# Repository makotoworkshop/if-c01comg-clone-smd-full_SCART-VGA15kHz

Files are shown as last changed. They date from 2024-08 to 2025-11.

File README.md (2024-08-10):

IF-C01COMG Clone board SMD Full size_SCART-VGA15kHz

This is a full sized version of the IF-C01COMG board for JVC pro monitors (TM-Hxx50CG) and some others...

It's basically the THT base board I made some months ago, with most components changed to SMD.

Credit goes to James Vanderloeff for the dual input idea.

Board is for now completely untested...

Finally this is a Kicad 5.1 project :D

You're welcome to clone, sell, re-design and whatever, see LICENSE.

(2021) Martin Hejnfelt (martin@hejnfelt.com)
This work is free. You can redistribute it and/or modify it under the
terms of the Do What The Fuck You Want To Public License, Version 2,
as published by Sam Hocevar. See the LICENSE file for more details.

—————————————————————————————

edit (2024) makotoworkshop.org

For more informations, see https://burogu.makotoworkshop.org/index.php?post/2024/08/08/jvc-rgb
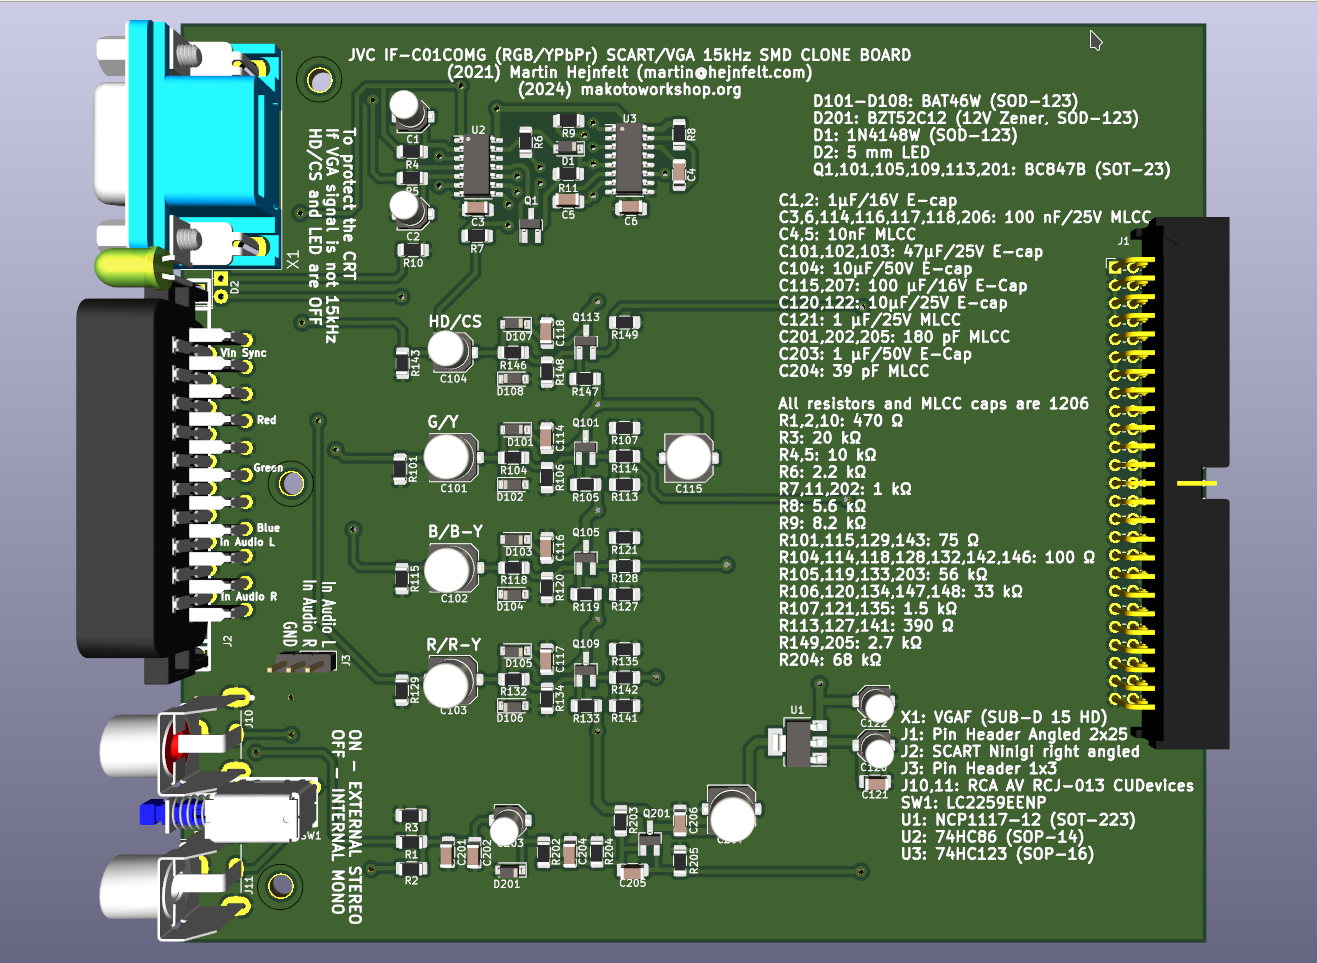
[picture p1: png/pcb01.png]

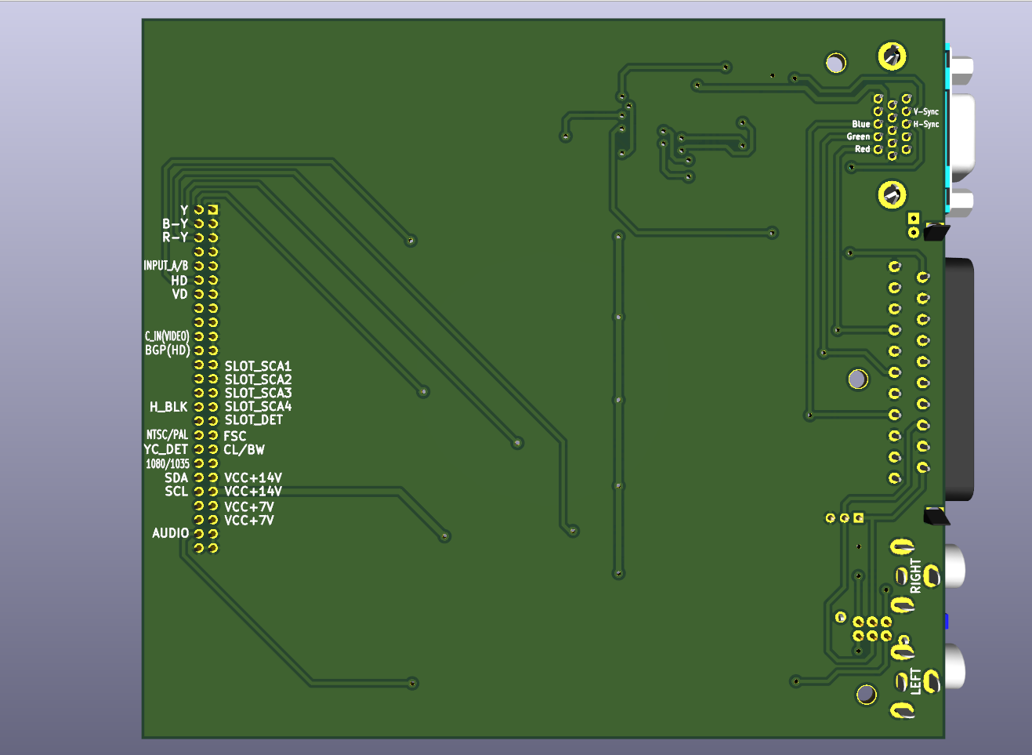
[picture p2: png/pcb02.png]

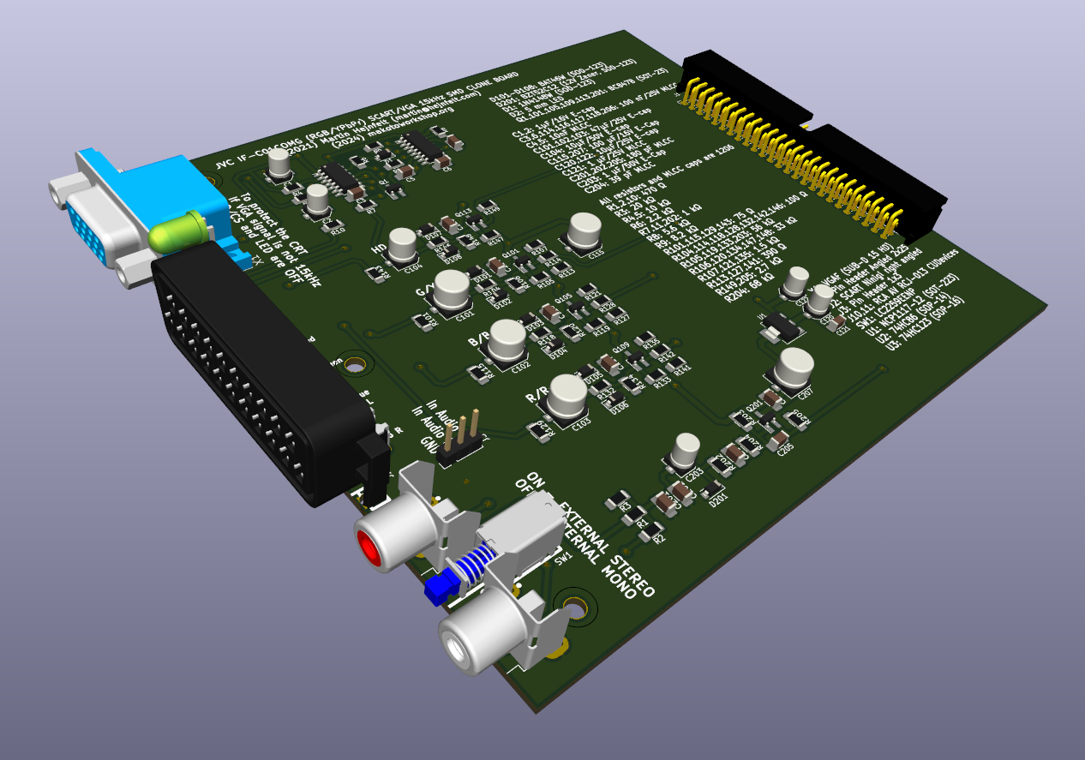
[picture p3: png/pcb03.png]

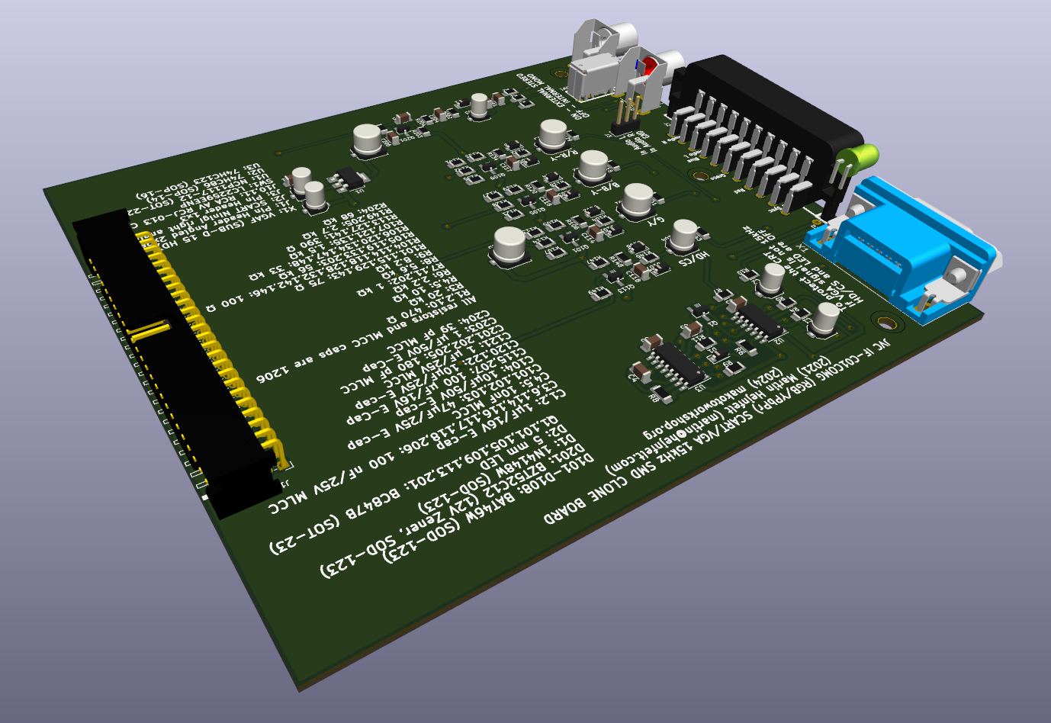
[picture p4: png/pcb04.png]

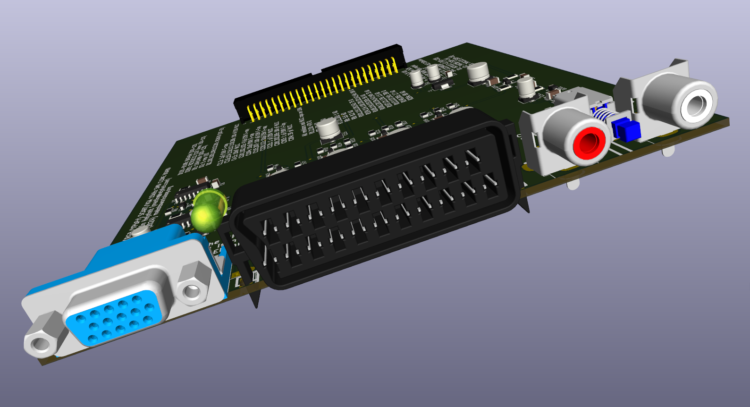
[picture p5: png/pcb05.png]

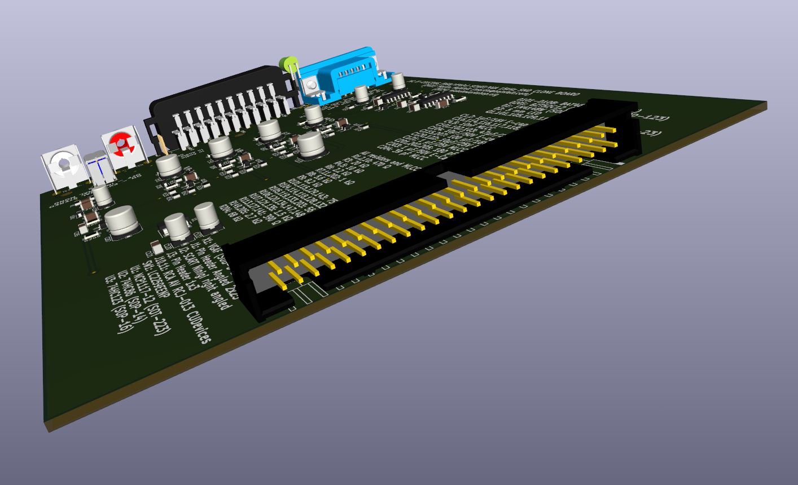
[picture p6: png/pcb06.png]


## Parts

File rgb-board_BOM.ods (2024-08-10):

Ref | Qnty | Stock | Value | Cmp name | Footprint | Description
C1, C2, | 2 | 19 | 1uF/16V | CP | Capacitor_SMD:C_Elec_4x5.4
C3, C6, C114, C116, C117, C118, C206, | 7 | 26 | 100nF | C | Capacitor_SMD:C_1206_3216Metric_Pad1.33x1.80mm_HandSolder
C4, C5, | 2 | 12 | 10nF | C | Capacitor_SMD:C_1206_3216Metric_Pad1.33x1.80mm_HandSolder
C101, C102, C103, | 3 | 20 | 47uF/25V | CP | Capacitor_SMD:C_Elec_6.3x5.4
C104, | 1 | 20 | 10uF/50V | CP | Capacitor_SMD:C_Elec_5x5.4
C115, C207, | 2 | 24 | 100uF/16V | CP | Capacitor_SMD:C_Elec_6.3x5.4
C120, C122, | 2 | 20 | 10uF/25V | CP | Capacitor_SMD:C_Elec_4x5.4
C121, | 1 | ALIE | 1uF/25V | C | Capacitor_SMD:C_1206_3216Metric_Pad1.33x1.80mm_HandSolder
C201, C202, C205, | 3 | ALIE | 180pF | C | Capacitor_SMD:C_1206_3216Metric_Pad1.33x1.80mm_HandSolder
C203, | 1 | 19 | 1uF/50V | CP | Capacitor_SMD:C_Elec_4x5.4
C204, | 1 | ALIE | 39pF | C | Capacitor_SMD:C_1206_3216Metric_Pad1.33x1.80mm_HandSolder
D1, | 1 | ALIE | 1N4148W | 1N4148W | Diode_SMD:D_SOD-123 | 75V 0.15A Fast Switching Diode, SOD-123
D2, | 1 | ok | LED_Small_Filled | LED_Small_Filled | LED_THT:LED_D5.0mm_Horizontal_O1.27mm_Z3.0mm | Light emitting diode, small symbol, filled shape
D101, D102, D103, D104, D105, D106, D107, D108, | 8 | ALIE | BAT46W | D | Diode_SMD:D_SOD-123
D201, | 1 | ALIE | BZT52C12 | D_Zener | Diode_SMD:D_SOD-123
J1, | 1 | ALIE | Conn_02x25_Odd_Even | Conn_02x25_Odd_Even | Pin_Headers:Pin_Header_Angled_2x25_Pitch2.54mm
J2, | 1 | ok | SCART-F | SCART-F | ninigi-scart-ra:NINIGI-SCART-RA
J10, J11, | 2 | ALIE | Conn_Coaxial | Conn_Coaxial | rcj-41x:RCJ-04X
Q1, | 1 | 199 | BC847B | BC847 | Package_TO_SOT_SMD:SOT-23_Handsoldering | 0.1A Ic, 45V Vce, Small Signal NPN Transistor, TO-92
Q101, Q105, Q109, Q113, Q201, | 5 | 199 | BC850C | Q_NPN_BEC | Package_TO_SOT_SMD:SOT-23_Handsoldering | NPN transistor, base/emitter/collector
R1, R2, R10, | 3 | 10 | 470R | R | Resistor_SMD:R_1206_3216Metric_Pad1.30x1.75mm_HandSolder
R3, | 1 | ALIE | 20K | R | Resistor_SMD:R_1206_3216Metric_Pad1.30x1.75mm_HandSolder
R4, R5, | 2 | 9 | 10k | R | Resistor_SMD:R_1206_3216Metric_Pad1.30x1.75mm_HandSolder
R6, | 1 | 14 | 2k2 | R | Resistor_SMD:R_1206_3216Metric_Pad1.30x1.75mm_HandSolder
R7, R11, R202, | 2 | ALIE | 1k | R | Resistor_SMD:R_1206_3216Metric_Pad1.30x1.75mm_HandSolder
R8, | 1 | ALIE | 5k6 | R | Resistor_SMD:R_1206_3216Metric_Pad1.30x1.75mm_HandSolder
R9, | 1 | ALIE | 8k2 | R | Resistor_SMD:R_1206_3216Metric_Pad1.30x1.75mm_HandSolder
R101, R115, R129, R143, | 4 | ALIE | 75R | R | Resistor_SMD:R_1206_3216Metric_Pad1.30x1.75mm_HandSolder
R104, R114, R118, R128, R132, R142, R146, | 7 | 26 | 100R | R | Resistor_SMD:R_1206_3216Metric_Pad1.30x1.75mm_HandSolder
R105, R119, R133, R203, | 4 | ALIE | 56k | R | Resistor_SMD:R_1206_3216Metric_Pad1.30x1.75mm_HandSolder
R106, R120, R134, R147, R148, | 5 | 10 | 33k | R | Resistor_SMD:R_1206_3216Metric_Pad1.30x1.75mm_HandSolder
R107, R121, R135, | 3 | ALIE | 1.5k | R | Resistor_SMD:R_1206_3216Metric_Pad1.30x1.75mm_HandSolder
R113, R127, R141, | 3 | ALIE | 390R | R | Resistor_SMD:R_1206_3216Metric_Pad1.30x1.75mm_HandSolder
R149, R205, | 2 | ALIE | 2.7k | R | Resistor_SMD:R_1206_3216Metric_Pad1.30x1.75mm_HandSolder
R204, | 1 | ALIE | 68K | R | Resistor_SMD:R_1206_3216Metric_Pad1.30x1.75mm_HandSolder
SW1, | 1 | 9 | SW_DPDT_x2 | SW_DPDT_x2 | LC2259:LC2259
U1, | 1 | ALIE | NCP1117-12 | NCP1117-12_SOT223 | Package_TO_SOT_SMD:SOT-223-3_TabPin2 | 1A Low drop-out regulator, Fixed Output 12V, SOT-223
U2, | 1 | ALIE | 74HC86 | 74HC86 | Package_SO:SOIC-14_3.9x8.7mm_P1.27mm | Quad 2-input XOR
U3, | 1 | ALIE | 74HC123 | 74HC123 | Package_SO:SOIC-16_3.9x9.9mm_P1.27mm | Dual retriggerable monostable multivibrator
X1, | 1 |  | VGAF | VGAF | HD15:HD15_B-HD15F

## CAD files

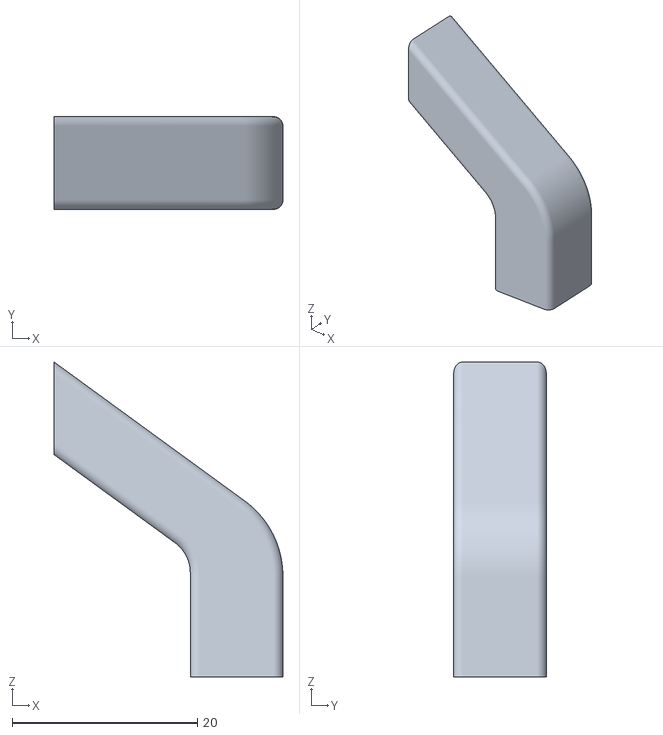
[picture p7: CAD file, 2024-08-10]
FreeCAD/Façade-ArcsNum003.stl
24.7 x 10.0 x 34.0

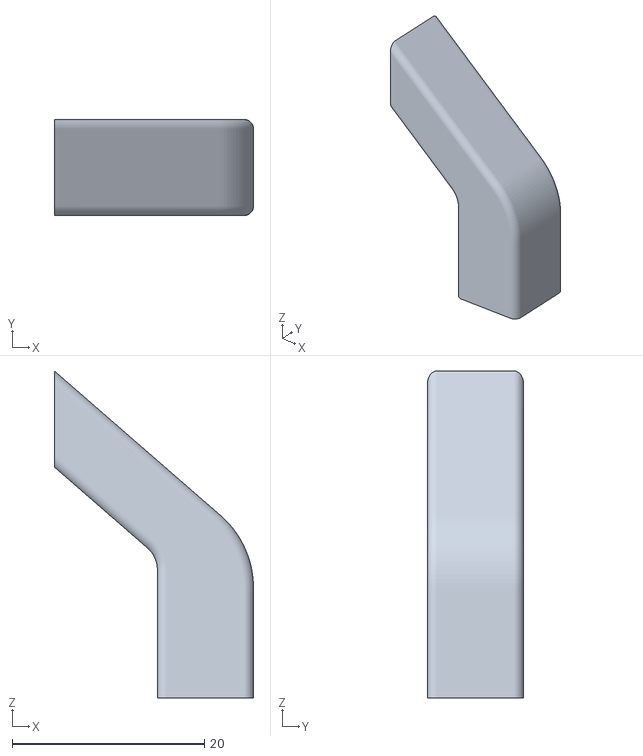
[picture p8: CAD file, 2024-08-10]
FreeCAD/Façade-ArcsNum002.stl
20.7 x 10.0 x 34.0

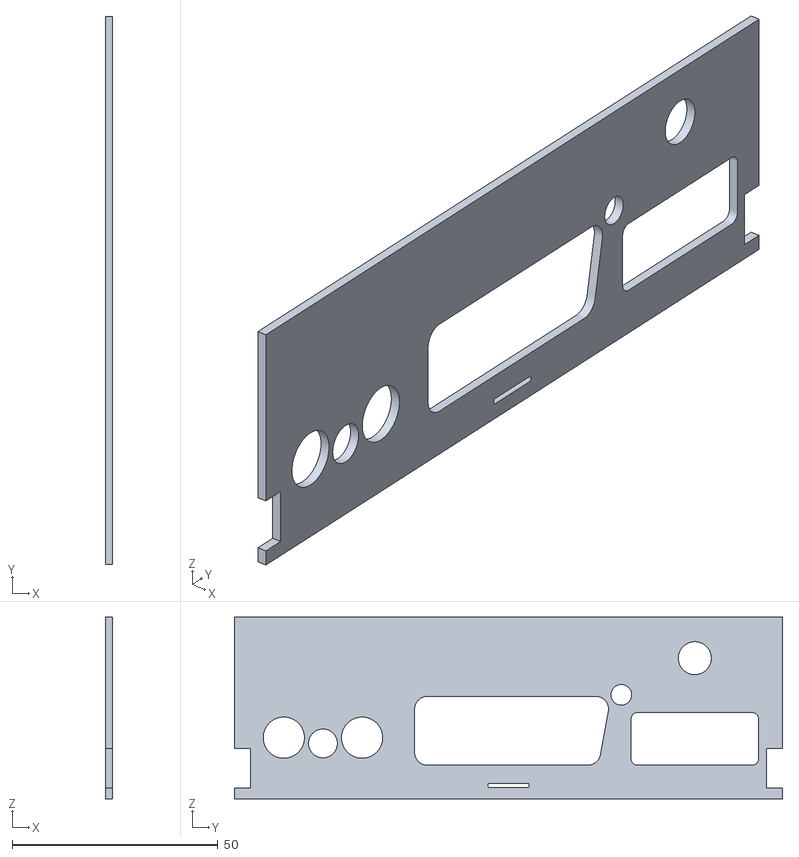
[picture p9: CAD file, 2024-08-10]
FreeCAD/Façade-Façade.stl
1.70 x 133.2 x 44.2

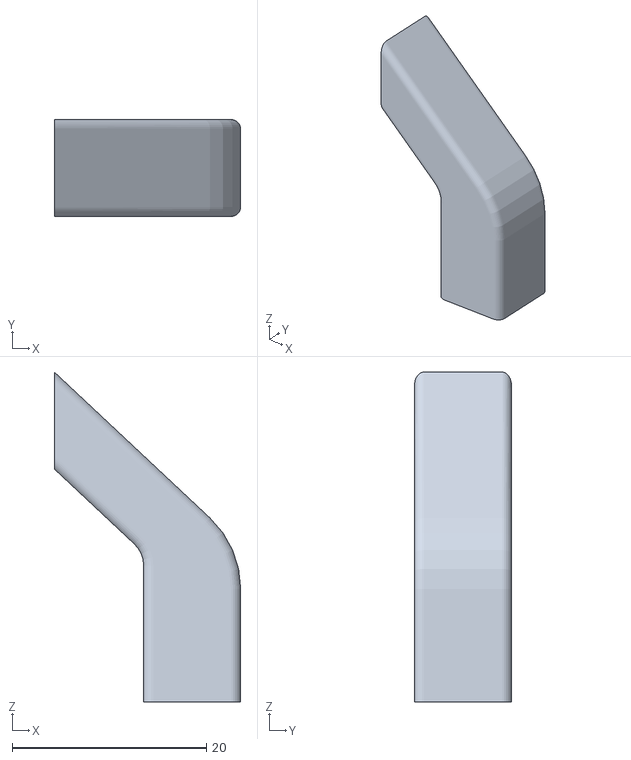
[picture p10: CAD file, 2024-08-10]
FreeCAD/Façade-ArcsNum1.stl
19.2 x 10.0 x 34.0

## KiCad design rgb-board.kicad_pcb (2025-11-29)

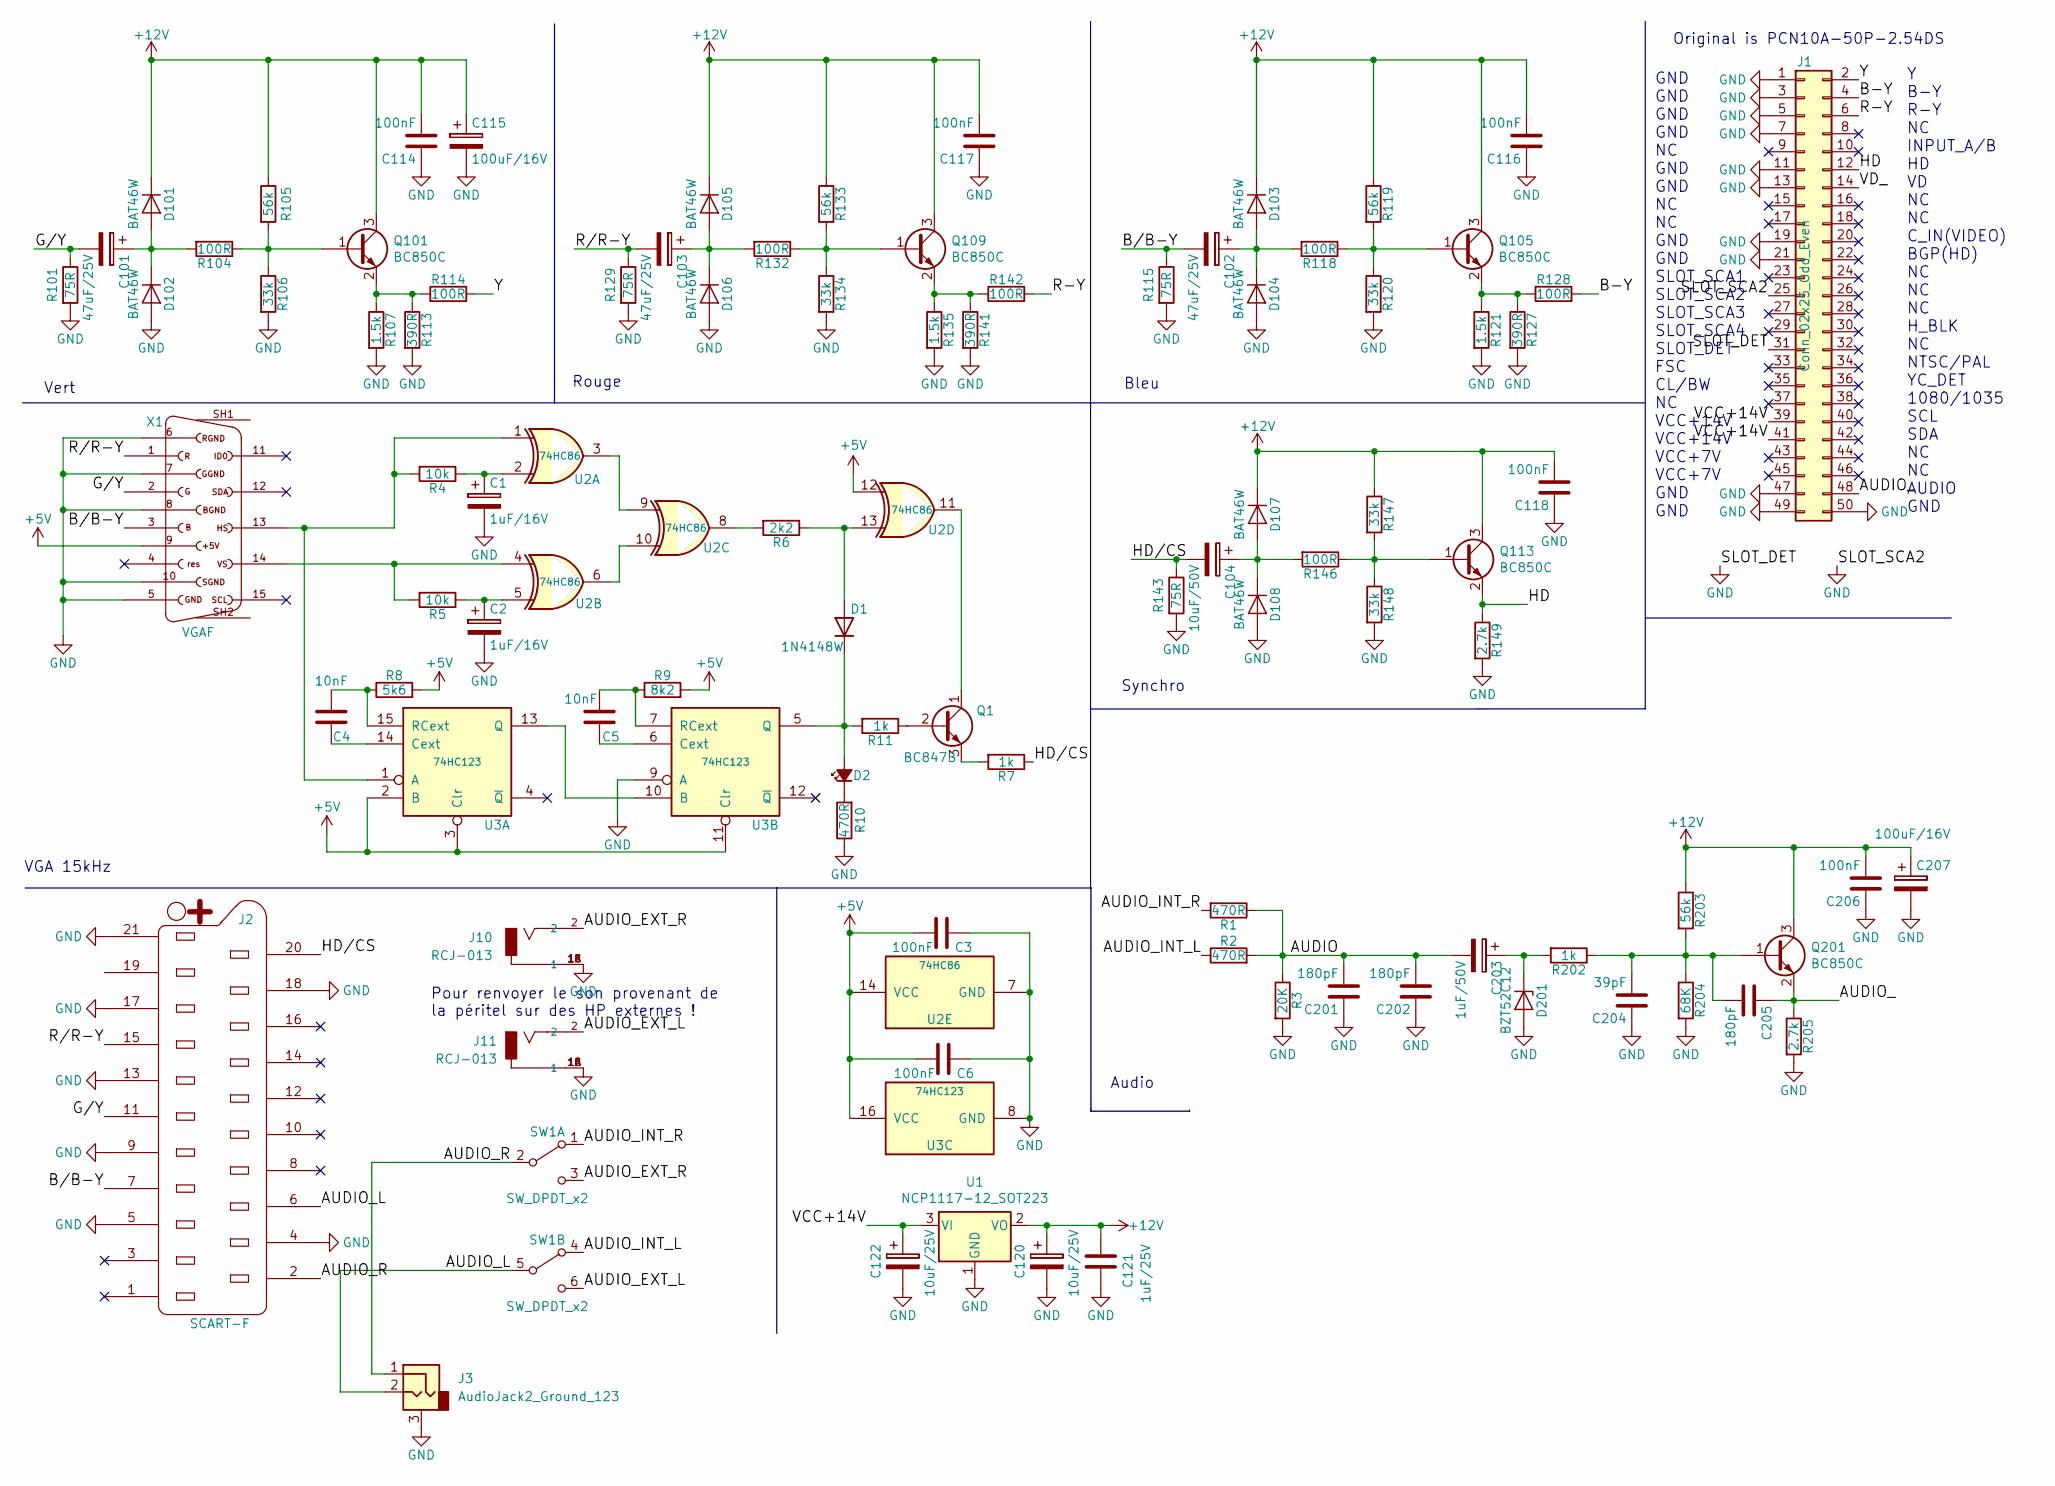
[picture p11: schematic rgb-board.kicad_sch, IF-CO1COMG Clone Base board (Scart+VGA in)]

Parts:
C1, C2: 1uF/16V; C_Elec_4x5.4
C3, C6, C114, C116, C117, C118, C206: 100nF; C_1206_3216Metric_Pad1.33x1.80mm_HandSolder
C4, C5: 10nF; C_1206_3216Metric_Pad1.33x1.80mm_HandSolder
C101, C102, C103: 47uF/25V; C_Elec_6.3x5.4
C104: 10uF/50V; C_Elec_5x5.4
C115, C207: 100uF/16V; C_Elec_6.3x5.4
C120, C122: 10uF/25V; C_Elec_4x5.4
C121: 1uF/25V; C_1206_3216Metric_Pad1.33x1.80mm_HandSolder
C201, C202, C205: 180pF; C_1206_3216Metric_Pad1.33x1.80mm_HandSolder
C203: 1uF/50V; C_Elec_4x5.4
C204: 39pF; C_1206_3216Metric_Pad1.33x1.80mm_HandSolder
D1: 1N4148W; D_SOD-123
D2: LED_Small_Filled; LED_D5.0mm_Horizontal_O1.27mm_Z3.0mm
D101, D102, D103, D104, D105, D106, D107, D108: BAT46W; D_SOD-123
D201: BZT52C12; D_SOD-123
J1: Conn_02x25_Odd_Even; Pin_Header_Angled_2x25_Pitch2.54mm
J2: SCART-F; NINIGI-SCART-RA
J3: AudioJack2_Ground_123; PinHeader_1x03_P2.54mm_Vertical
J10, J11: RCJ-013; CUI_RCJ-013; PART_REV B
Q1: BC847B; SOT-23_Handsoldering
Q101, Q105, Q109, Q113, Q201: BC850C; SOT-23_Handsoldering
R1, R2, R10: 470R; R_1206_3216Metric_Pad1.30x1.75mm_HandSolder
R3: 20K; R_1206_3216Metric_Pad1.30x1.75mm_HandSolder
R4, R5: 10k; R_1206_3216Metric_Pad1.30x1.75mm_HandSolder
R6: 2k2; R_1206_3216Metric_Pad1.30x1.75mm_HandSolder
R7, R11, R202: 1k; R_1206_3216Metric_Pad1.30x1.75mm_HandSolder
R8: 5k6; R_1206_3216Metric_Pad1.30x1.75mm_HandSolder
R9: 8k2; R_1206_3216Metric_Pad1.30x1.75mm_HandSolder
R101, R115, R129, R143: 75R; R_1206_3216Metric_Pad1.30x1.75mm_HandSolder
R104, R114, R118, R128, R132, R142, R146: 100R; R_1206_3216Metric_Pad1.30x1.75mm_HandSolder
R105, R119, R133, R203: 56k; R_1206_3216Metric_Pad1.30x1.75mm_HandSolder
R106, R120, R134, R147, R148: 33k; R_1206_3216Metric_Pad1.30x1.75mm_HandSolder
R107, R121, R135: 1.5k; R_1206_3216Metric_Pad1.30x1.75mm_HandSolder
R113, R127, R141: 390R; R_1206_3216Metric_Pad1.30x1.75mm_HandSolder
R149, R205: 2.7k; R_1206_3216Metric_Pad1.30x1.75mm_HandSolder
R204: 68K; R_1206_3216Metric_Pad1.30x1.75mm_HandSolder
SW1: SW_DPDT_x2; LC2259
U1: NCP1117-12_SOT223; SOT-223-3_TabPin2
U2: 74HC86; SOIC-14_3.9x8.7mm_P1.27mm
U3: 74HC123; SOIC-16_3.9x9.9mm_P1.27mm
X1: VGAF; HD15_B-HD15F

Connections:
+5V: C3.2, C6.2, R8.2, R9.2, U2.12, U2.14 (VCC), U3.2 (B), U3.3 (Clr), U3.11 (Clr), U3.16 (VCC), X1.9; also elsewhere on the board
+12V: C114.2, C115.1, C116.2, C117.2, C118.2, C120.1, C121.2, C206.2, C207.1, D101.1 (K), D103.1 (K), D105.1 (K), D107.1 (K), Q101.3 (C), Q105.3 (C), Q109.3 (C), Q113.3 (C), Q201.3 (C), R105.1, R119.1, R133.1, R147.1, R203.1, U1.2 (VO)
/AUDIO: C201.2, C202.2, C203.2, R1.1, R2.2, R3.1
/AUDIO_: C205.1, J1.48, Q201.2 (E), R205.1
/AUDIO_EXT_L: J11.2, SW1.6 (C)
/AUDIO_EXT_R: J10.2, SW1.3 (C)
/AUDIO_INT_L: R2.1, SW1.4 (A)
/AUDIO_INT_R: R1.2, SW1.1 (A)
/AUDIO_L: J2.6, J3.2, SW1.5 (B)
/AUDIO_R: J2.2, J3.1, SW1.2 (B)
/B-Y: J1.4, R128.2
/B/B-Y: C102.2, J2.7, R115.1, X1.3
/G/Y: C101.2, J2.11, R101.1, X1.2
/HD: J1.12, Q113.2 (E), R149.1
/HD/CS: C104.2, J2.20, R7.1, R143.1
/R-Y: J1.6, R142.2
/R/R-Y: C103.2, J2.15, R129.1, X1.1
/VCC+14V: C122.1, J1.39, J1.41, U1.3 (VI); also elsewhere on the board
/VD_: J1.14
/Y: J1.2, R114.2
GND: C1.2, C2.2, C3.1, C6.1, C114.1, C115.2, C116.1, C117.1, C118.1, C120.2, C121.1, C122.2, C201.1, C202.1, C204.1, C206.1, C207.2, D102.2 (A), D104.2 (A), D106.2 (A), D108.2 (A), D201.2 (A), J1.1, J1.3, J1.5, J1.7, J1.11, J1.13, J1.19, J1.21, J1.25, J1.31, J1.47, J1.49, J1.50, J2.4, J2.5, J2.9, J2.13, J2.17, J2.18, J2.21, J3.3, J10.1A (1), J10.1B (1), J10.1C (1), J11.1A (1), J11.1B (1), J11.1C (1), R3.2, R10.1, R101.2, R106.2, R107.2, R113.2, R115.2, R120.2, R121.2, R127.2, R129.2, R134.2, R135.2, R141.2, R143.2, R148.2, R149.2, R204.2, R205.2, U1.1 (GND), U2.7 (GND), U3.8 (GND), U3.9 (A), X1.5, X1.6, X1.7, X1.8, X1.10; also elsewhere on the board
unnamed: C1.1, R4.1, U2.2
unnamed: C2.1, R5.1, U2.5
unnamed: D1.2 (A), R6.1, U2.13
unnamed: D1.1 (K), D2.2 (A), R11.2, U3.5 (Q)
unnamed: D2.1 (K), R10.2
unnamed: C101.1, D101.2 (A), D102.1 (K), R104.2
unnamed: C102.1, D103.2 (A), D104.1 (K), R118.2
unnamed: C103.1, D105.2 (A), D106.1 (K), R132.2
unnamed: C104.1, D107.2 (A), D108.1 (K), R146.2
unnamed: C203.1, D201.1 (K), R202.2
unnamed: Q1.2 (B), R11.1
unnamed: Q1.1 (C), U2.11
unnamed: Q1.3 (E), R7.2
unnamed: Q101.1 (B), R104.1, R105.2, R106.1
unnamed: Q101.2 (E), R107.1, R113.1, R114.1
unnamed: Q105.1 (B), R118.1, R119.2, R120.1
unnamed: Q105.2 (E), R121.1, R127.1, R128.1
unnamed: Q109.1 (B), R132.1, R133.2, R134.1
unnamed: Q109.2 (E), R135.1, R141.1, R142.1
unnamed: Q113.1 (B), R146.1, R147.2, R148.1
unnamed: C204.2, C205.2, Q201.1 (B), R202.1, R203.2, R204.1
unnamed: R5.2, U2.4, X1.14
unnamed: R6.2, U2.8
unnamed: U2.3, U2.9
unnamed: U2.6, U2.10
unnamed: R4.2, U2.1, U3.1 (A), X1.13
unnamed: C4.1, U3.14 (Cext)
unnamed: U3.10 (B), U3.13 (Q)
unnamed: C4.2, R8.1, U3.15 (RCext)
unnamed: C5.2, U3.6 (Cext)
unnamed: C5.1, R9.1, U3.7 (RCext)

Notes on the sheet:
Bleu
Pour renvoyer le son provenant de la péritel sur des HP externes !
Vert
Original is PCN10A-50P-2.54DS
Synchro
Y B-Y R-Y NC INPUT_A/B HD VD NC NC C_IN(VIDEO) BGP(HD) NC NC NC H_BLK NC NTSC/PAL YC_DET 1080/1035 SCL SDA NC NC AUDIO GND
Audio
GND GND GND GND NC GND GND NC NC GND GND SLOT_SCA1 SLOT_SCA2 SLOT_SCA3 SLOT_SCA4 SLOT_DET FSC CL/BW NC VCC+14V VCC+14V VCC+7V VCC+7V GND GND
VGA 15kHz
Rouge

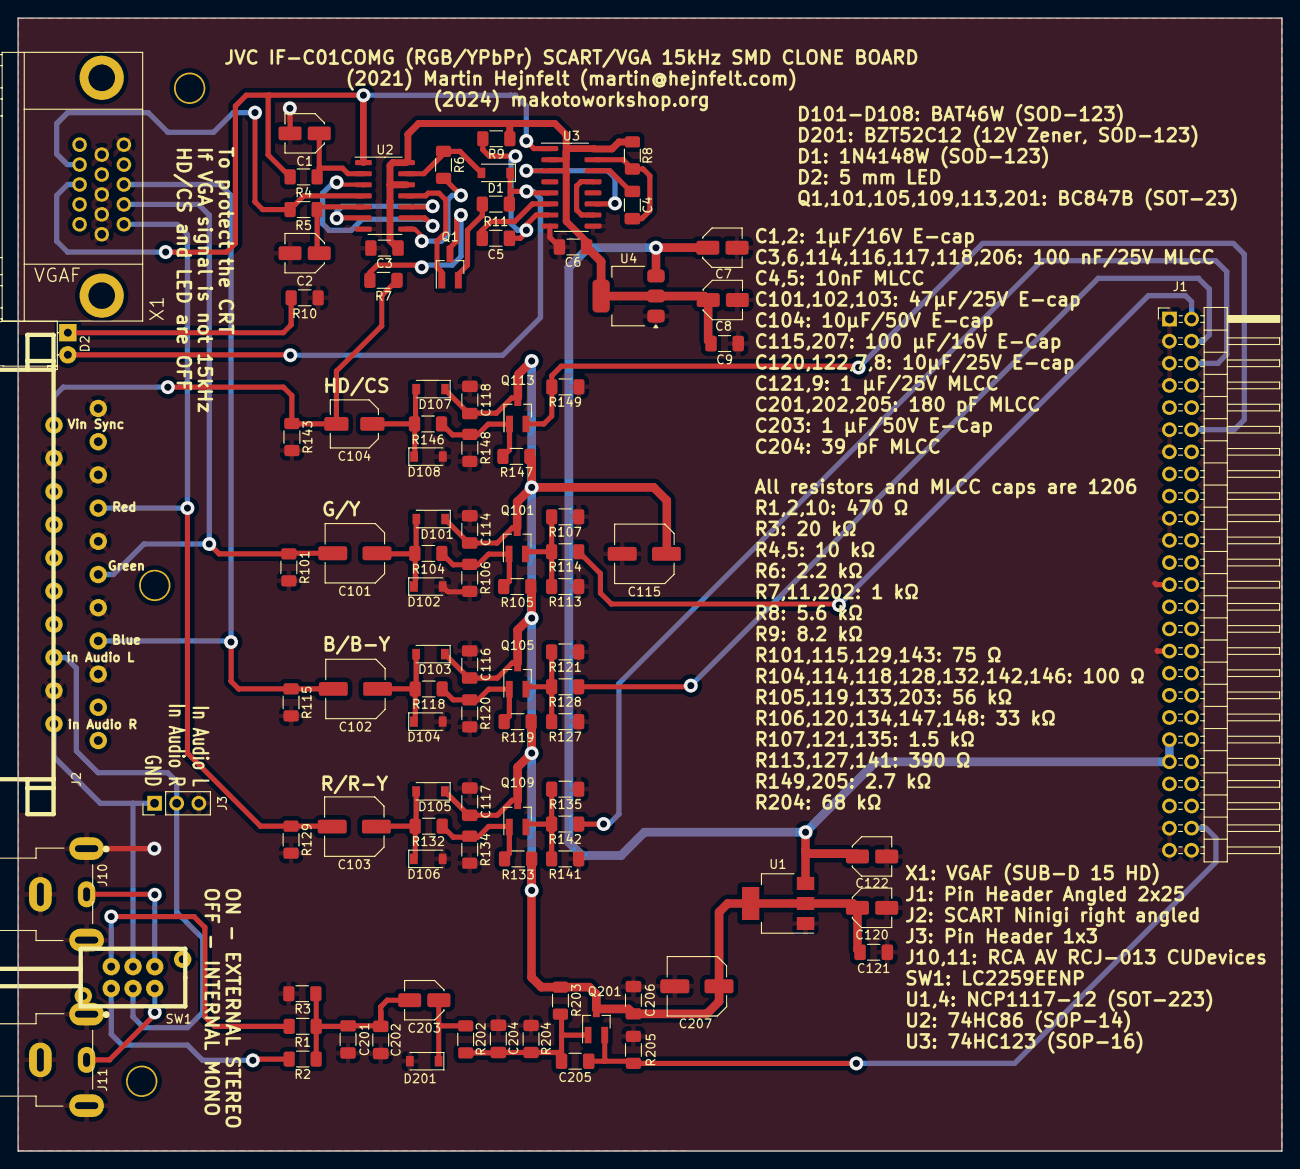
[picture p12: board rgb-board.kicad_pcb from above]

Board: 2 copper layers, 145.0 x 130.0 mm, 100 parts (0 on the bottom side), 51 nets.

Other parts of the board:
C7, C8: 10uF/25V; C_Elec_4x5.4
C9: 1uF/25V; C_1206_3216Metric_Pad1.33x1.80mm_HandSolder
J4, J4#2, J4#3: TEST_1P; MountingHole_3.2mm_M3
U4: NCP1117-5_SOT223; SOT-223-3_TabPin2

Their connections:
+5V: C8.1, C9.2, U4.2 (VO); also elsewhere on the board
/VCC+14V: C7.1, U4.3 (VI); also elsewhere on the board
GND: C7.2, C8.2, C9.1, U4.1 (GND); also elsewhere on the board

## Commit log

2025-11-29 Update rgb-board.kicad_pro
    5V-corrigé
2025-11-29 Update rgb-board.kicad_pcb
    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
    [rgb-board.kicad_pcb]
